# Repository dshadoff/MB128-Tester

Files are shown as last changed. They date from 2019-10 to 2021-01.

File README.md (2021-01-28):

# MB128-Tester
This project contains both a PC board to control (Backup, Restore, Test) PC Engine
Memory Base 128 devices, as well as the control software for that PC board.

The original PC board is based on an 'Adafruit Feather M0 Adalogger' microcontroller board, which
directly interfaces to PC Engine Memory Base 128 devices.

There is also an updated version which is based on the Seeed Studios Wio Terminal device, which is
more of a finished all-in-one unit with a screen.

This repository holds the software which runs on those devices, as well as the boards' design files.

The sketch was built within the Arduino IDE, but I found that the digitalWrite() and digitalRead()
functions were too slow: ~1uS per call, when I needed 3 to 4 times that speed.

Moreover, they could only manipulate one pin at a time, when I generally needed to write 2, or read 4.

As a result, you will see direct port reads/writes to the Cortex M0 (or M4) ports... see the comments at the
top of the sketch if this is confusing.

(Note: Older versions of this sketch were written for an older version of the board, which didn't have
status LEDs or pushbutton switches, and automatically started to read the MB128 at boot-up time.)

Instructions on use:
--------------------

To use any of the functionality, ensure that the MB128 is plugged into the port, and an SDCard is
inserted into the SDCard slot of the Microcontroller board.  Finally, then attach the USB cable
in order to apply power ot the board.

- M0 Adalogger board:
A short self-test will take place, and all of the LEDs will flash briefly.  Once this has completed
and the Feather's green LED is on, you may press a button.

- Wio Terminal:
A short self-test will take place, with status updates appearing on screen.  Once this has completed,
the screen will display a choice of operations (associated with the buttons across the top edge).

Backup:
-------
The device will backup the contents of the MB128 onto the SDCard, creating a file in the root
directory, with the filename: 'MB128_xx.SAV' (where 'xx' is a 2-digit number).  Multiple versions
of backups will be added to the SDCard until 99 versions have been reached.
A backup takes slightly over 10 seconds.

Restore:
--------
The device will use the highest-numbered 'MB128_xx.SAV' file in the root directory of the card,
and load the contents into the MB128.
A restore takes slightly over 10 seconds.

Test:
-----
The device will first create a temporary backup of the contents of the device, then will write,
read, and verify test patterns to all location on the MB128, finally restoring the original
contents.  The backup is saved into a file named 'TESTTEMP.BKP' in the root directory of the
SDCard.
A test takes slightly over one minute.

Error conditions:
-----------------
- If the 'SDCard Error' LED lights up at startup, there is a problem with the SDCard
- If the 'MB128 Error' LED lights up at startup, there is a problem with the MB128
(On the Wio Terminal version, clear error messages will appear on the screen).

- If either of the above LEDs go into a flashing state, this is an error which happened during
the process of reading or writing.  Please reset the device and/or turn the power off and back on

- In order to reset the device, there is a small pushbutton on the  microcontroller board. Do
not push this under normal circumstances, but you can press it if there is a flashing LED on
the MB128 reader.  If pressed, the MB128 may be interrupted in the middle of a protocol, causing
errors immedaitely afterward.  If this happens, unplug the MB128 from the reader, wait several
seconds, and plug it back in.  Then reset the microcontroller once again.

Additional information:
-----------------------
- If the USB is connected to a PC, and a terminal program is opened (19200 baud) for the
pseudo-serial port, messages indicating progress or errors will be displayed.

Original Board (Adalogger M0)
-----------------------------
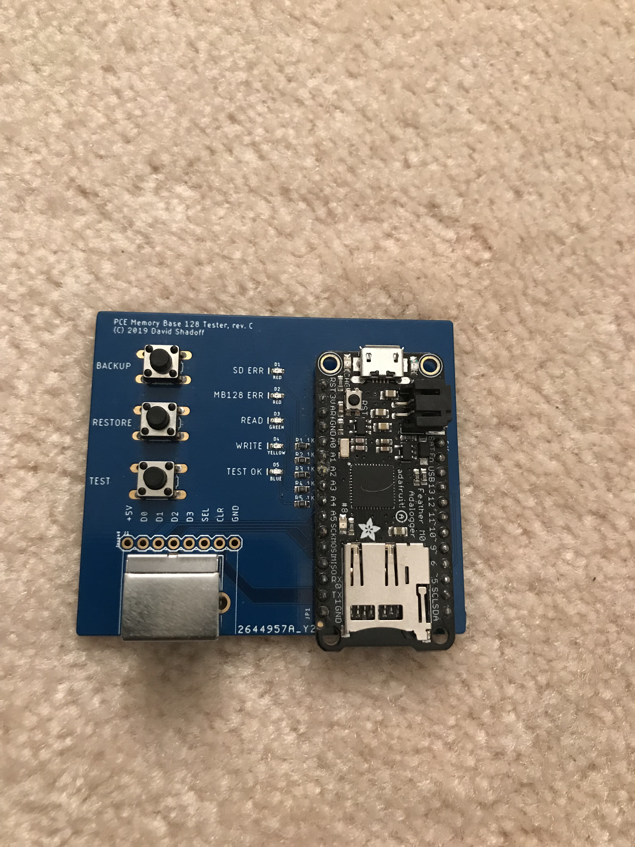
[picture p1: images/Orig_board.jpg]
Original Board


Wio Terminal (Rev. A, in use)
-----------------------------
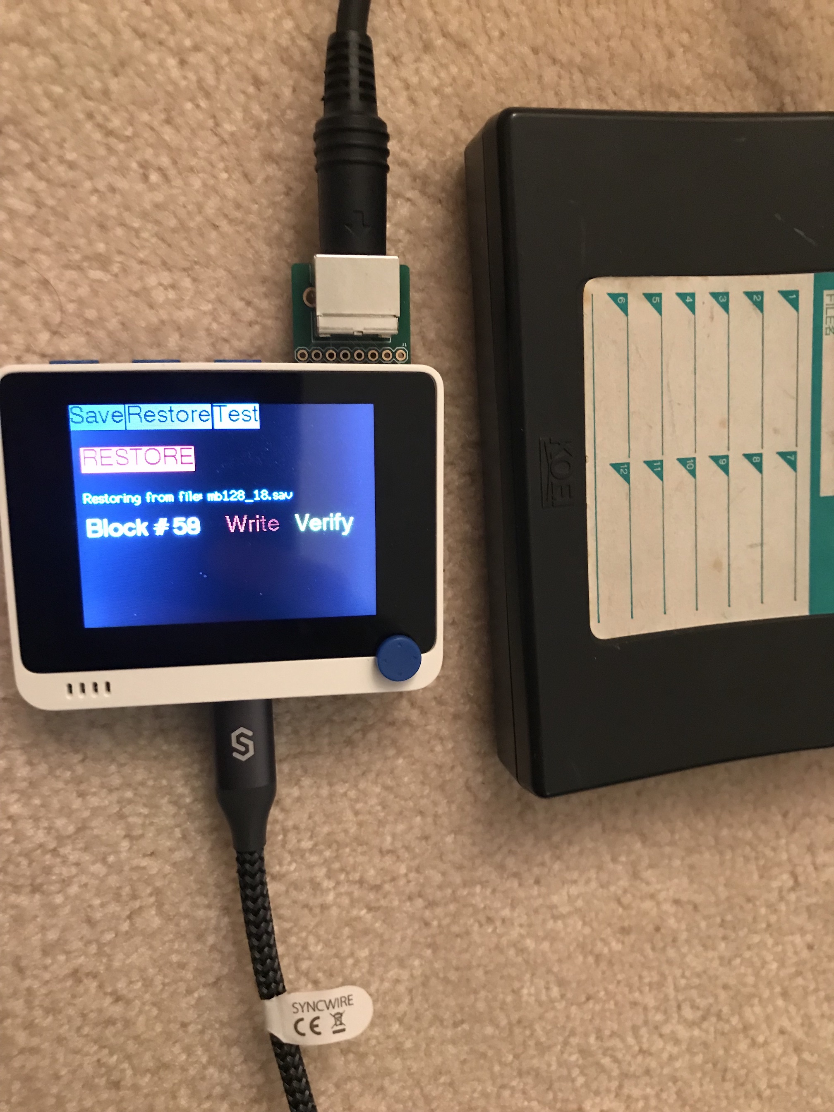
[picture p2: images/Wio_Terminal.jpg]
Wio_Terminal


Daughterboard
-------------
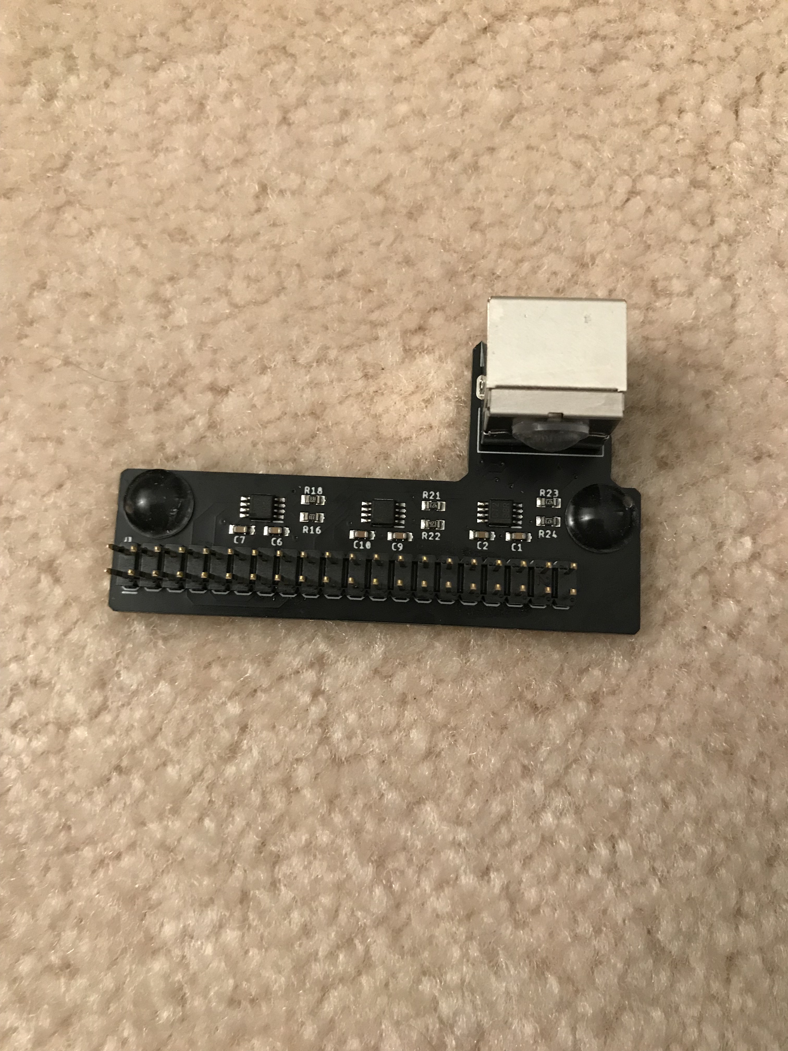
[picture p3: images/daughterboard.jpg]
Daughterboard


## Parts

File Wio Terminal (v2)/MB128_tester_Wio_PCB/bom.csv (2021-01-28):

Qty | Designator | Footprint | Comment | LCSC Part # (optional) | Description (optional)
6 | C1, C2, C6, C7, C9, C10 | C0603 | 0.1uF 50V | C14663 | Yageo CC0603KRX7R9BB104 100NF 50V 0603
2 | R16, R18 | R0603 | 330 ohm 1% | C23138 | Uniroyal Elec 0603WAF3300T5E 0603
4 | R21, R22, R23, R24 | R0603 | 47K 1% | C25819 | Uniroyal Elec 0603WAF4702T5E 0603
1 | J3 | 2X20 | Do not mount | Do not mount | Multi connection point. Often used as Generic Header-pin footprint for 0.1 inch spaced/style header connections
1 | J2 | MD80SGK | Do not mount | Do not mount | Circular DIN Connectors mini-DIN, 8P jack, rt, through hole, full shield
3 | IC1, IC2, IC3 | SM-8_2.8x3.0x0.65P | SN74LVC2T45DCTR | C22672 | 2-Bit Bus Transceiver, Translation SSOP8 SN74LVC2T45DCTR, Voltage Level Translator, Bus Transceiver LVC, 3-State 1.65

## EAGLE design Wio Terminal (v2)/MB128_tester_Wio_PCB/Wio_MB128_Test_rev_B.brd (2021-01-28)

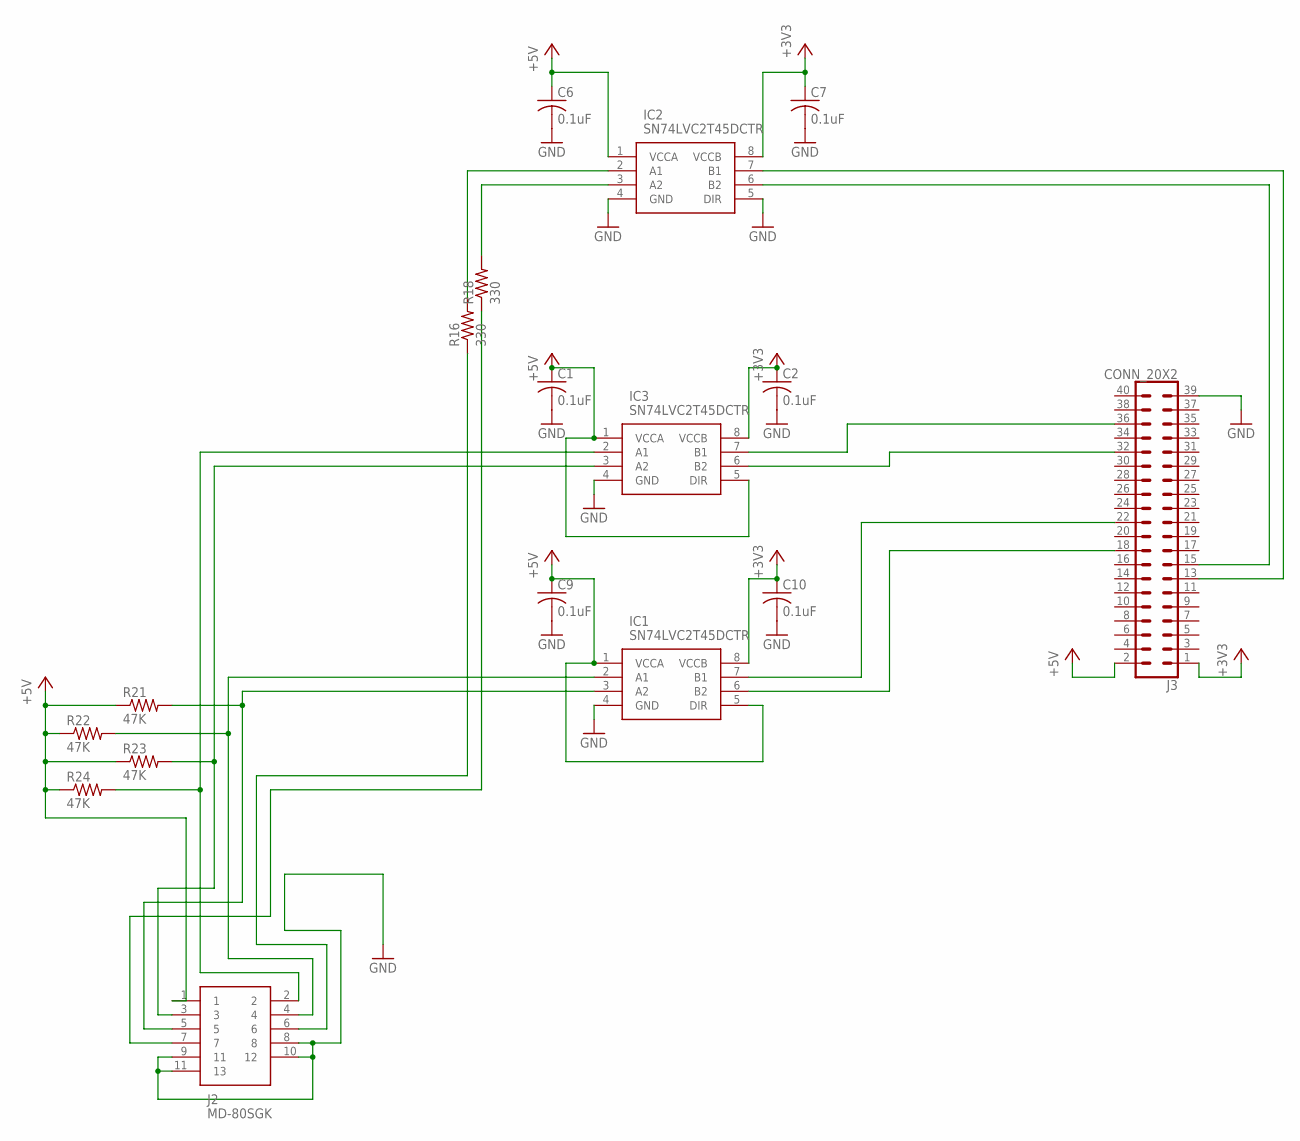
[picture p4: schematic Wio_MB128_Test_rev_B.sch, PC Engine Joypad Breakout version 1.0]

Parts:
C1, C2, C6, C7, C9, C10: 0.1uF; C0603
IC1, IC2, IC3: SN74LVC2T45DCTR; SOP65P400X130-8N
J2: MD-80SGK; MD80SGK
J3: CONN_20X2; 2X20
R16, R18: 330; R0603
R21, R22, R23, R24: 47K; R0603

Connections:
+3V3: C2.1, C7.1, C10.1, IC1.8 (VCCB), IC2.8 (VCCB), IC3.8 (VCCB), J3.1
+5V: C1.1, C6.1, C9.1, IC1.1 (VCCA), IC1.5 (DIR), IC2.1 (VCCA), IC3.1 (VCCA), IC3.5 (DIR), J2.1, J3.2, R21.1, R22.1, R23.1, R24.1
CLR: J2.7, R18.1
D11: IC1.7 (B1), J3.22
GND: C1.2, C2.2, C6.2, C7.2, C9.2, C10.2, IC1.4 (GND), IC2.4 (GND), IC2.5 (DIR), IC3.4 (GND), J2.8, J2.9 (11), J2.10 (12), J2.11 (13), J3.39
unnamed: IC2.7 (B1), J3.13
unnamed: IC3.3 (A2), J2.3, R23.2
unnamed: IC3.2 (A1), J2.2, R24.2
unnamed: IC2.6 (B2), J3.15
unnamed: IC1.6 (B2), J3.18
unnamed: IC2.2 (A1), R16.2
unnamed: IC1.2 (A1), J2.4, R22.2
unnamed: IC1.3 (A2), J2.5, R21.2
unnamed: IC2.3 (A2), R18.2
unnamed: IC3.7 (B1), J3.36
unnamed: IC3.6 (B2), J3.32
SEL: J2.6, R16.1

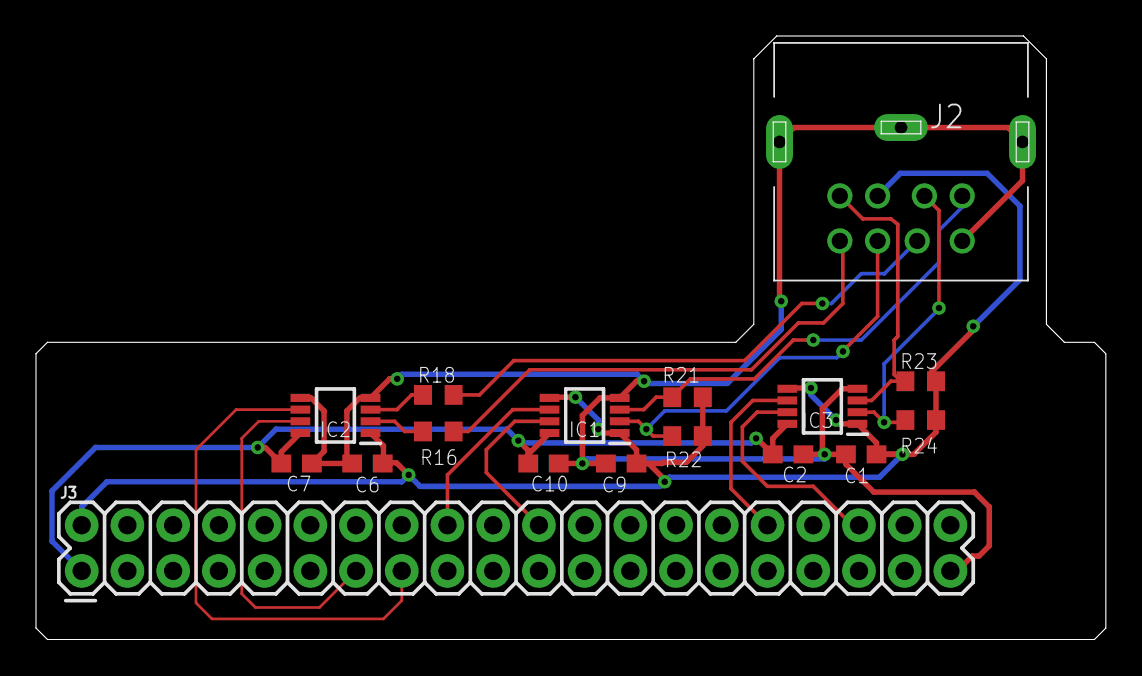
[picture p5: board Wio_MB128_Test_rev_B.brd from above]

Board: 2 copper layers, 59.4 x 33.5 mm, 17 parts (0 on the bottom side), 17 nets.

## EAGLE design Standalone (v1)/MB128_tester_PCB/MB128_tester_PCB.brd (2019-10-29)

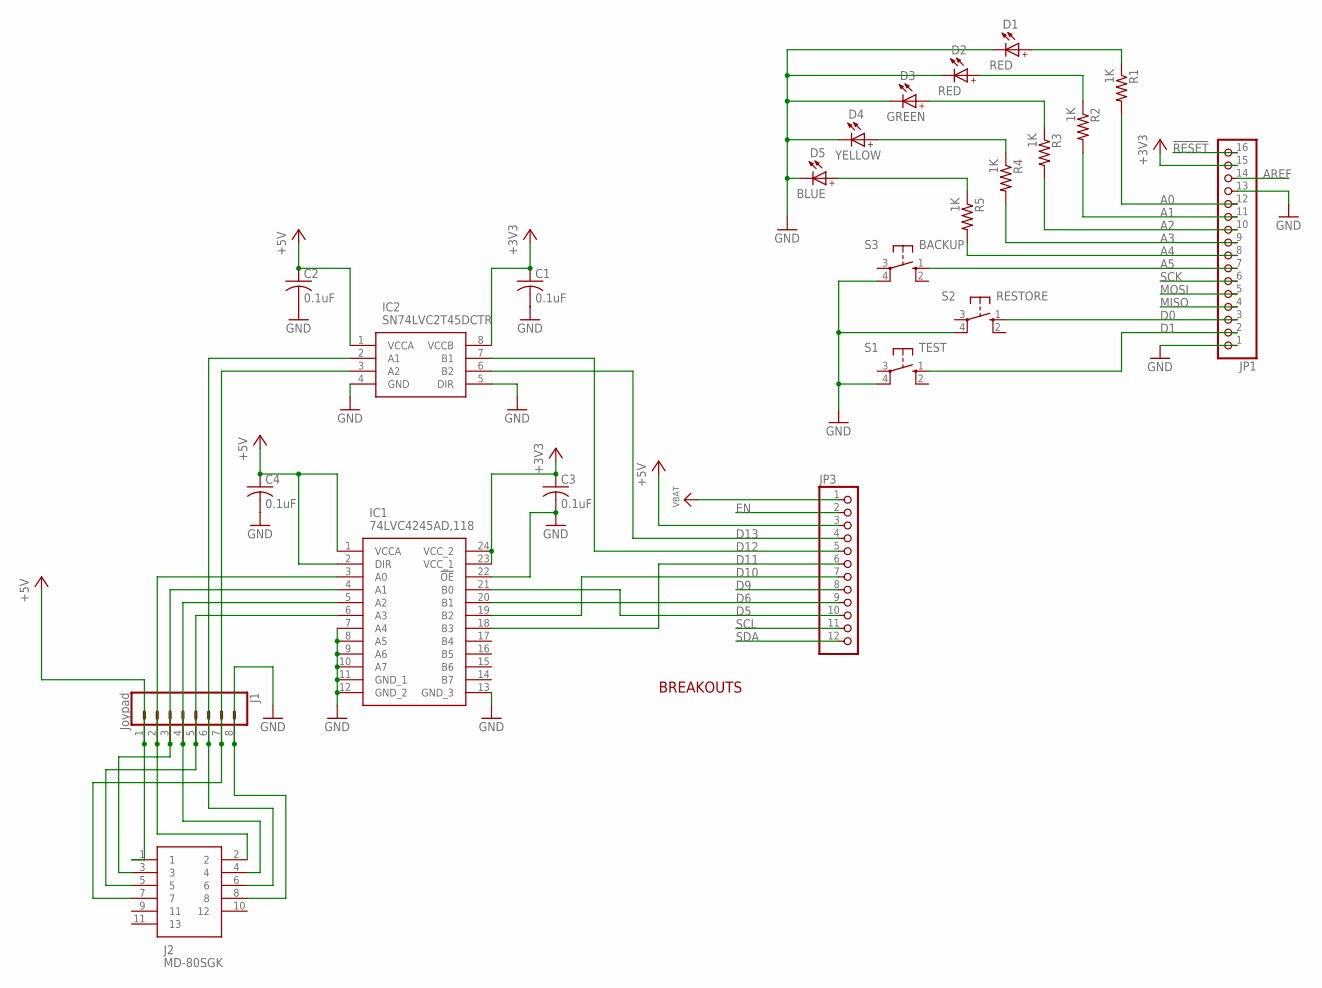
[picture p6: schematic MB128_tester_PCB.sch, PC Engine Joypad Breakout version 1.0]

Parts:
C1, C2, C3, C4: 0.1uF; C0805
D1, D2: RED; WL-SMCC_0603_R/Y/V
D3: GREEN; WL-SMCC_0603_R/Y/V
D4: YELLOW; WL-SMCC_0603_R/Y/V
D5: BLUE; WL-SMCC_0603_R/Y/V
IC1: 74LVC4245AD,118; SOIC127P1032X265-24N
IC2: SN74LVC2T45DCTR; SOP65P400X130-8N
J1: Joypad; 1X08
J2: MD-80SGK; MD80SGK
JP1: HEADER-1X16ROUND; 1X16_ROUND
JP3: HEADER-1X12; 1X12_ROUND
R1, R2, R3, R4, R5: 1K; R0603
S1: TEST; B3F-10XX
S2: RESTORE; B3F-10XX
S3: BACKUP; B3F-10XX

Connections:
!RESET: JP1.16
+3V3: C1.1, C3.1, IC1.23 (VCC_1), IC1.24 (VCC_2), IC2.8 (VCCB), JP1.15
+5V: C2.1, C4.1, IC1.1 (VCCA), IC1.2 (DIR), IC2.1 (VCCA), J1.1, J2.1, JP3.3
A0: JP1.12, R1.2
A1: JP1.11, R2.2
A2: JP1.10, R3.2
A3: JP1.9, R4.2
A4: JP1.8, R5.2
A5: JP1.7, S3.1 (S)
AREF: JP1.14
D0: JP1.3, S2.1 (S)
D1: JP1.2, S1.1 (S)
D5: IC1.21 (B0), JP3.10
D6: IC1.20 (B1), JP3.9
D9: JP3.8
D10: IC1.19 (B2), JP3.7
D11: IC1.18 (B3), JP3.6
D12: IC2.7 (B1), JP3.5
D13: IC2.6 (B2), JP3.4
EN: JP3.2
GND: C1.2, C2.2, C3.2, C4.2, D1.1 (C), D2.1 (C), D3.1 (C), D4.1 (C), D5.1 (C), IC1.7 (A4), IC1.8 (A5), IC1.9 (A6), IC1.10 (A7), IC1.11 (GND_1), IC1.12 (GND_2), IC1.13 (GND_3), IC1.22 (!OE), IC2.4 (GND), IC2.5 (DIR), J1.8, J2.8, JP1.1, JP1.13, S1.4 (P1), S2.4 (P1), S3.4 (P1)
MISO: JP1.4
MOSI: JP1.5
unnamed: D1.2 (A), R1.1
unnamed: IC1.4 (A1), J1.3, J2.3
unnamed: IC1.3 (A0), J1.2, J2.2
unnamed: IC1.5 (A2), J1.4, J2.4
unnamed: IC1.6 (A3), J1.5, J2.5
unnamed: IC2.2 (A1), J1.6, J2.6
unnamed: IC2.3 (A2), J1.7, J2.7
unnamed: D2.2 (A), R2.1
unnamed: D3.2 (A), R3.1
unnamed: D4.2 (A), R4.1
unnamed: D5.2 (A), R5.1
SCK: JP1.6
SCL: JP3.11
SDA: JP3.12
VBAT: JP3.1

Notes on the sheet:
BREAKOUTS

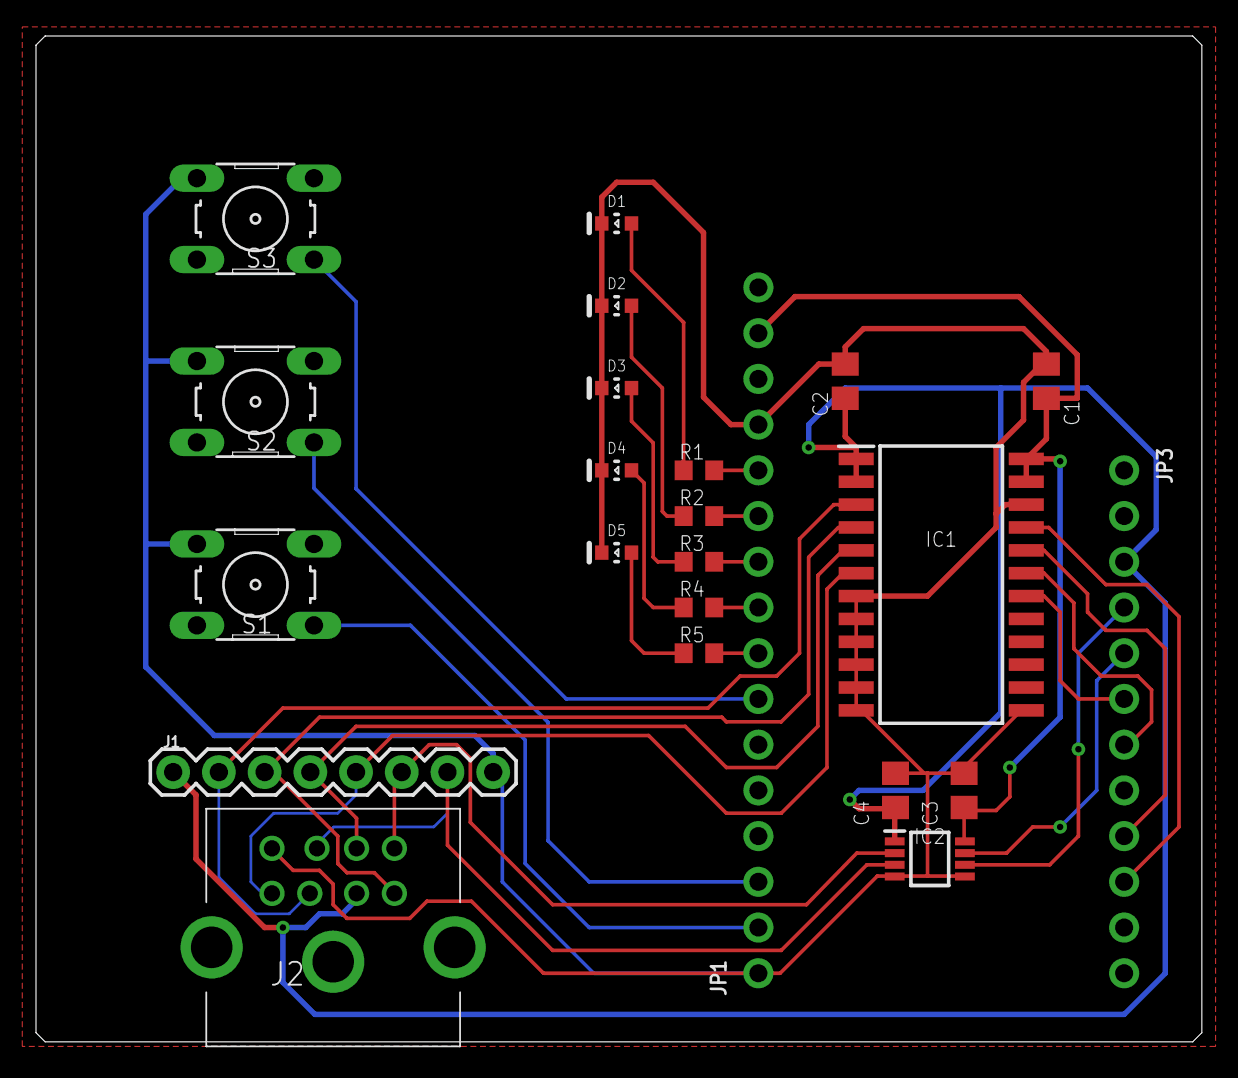
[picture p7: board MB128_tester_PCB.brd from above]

Board: 2 copper layers, 64.8 x 55.9 mm, 23 parts (0 on the bottom side), 28 nets.

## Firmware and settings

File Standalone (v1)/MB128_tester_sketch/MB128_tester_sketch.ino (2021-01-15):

#include <SD.h>

//
// This sketch implements a MB128 host
// To extract or restore the contents of the MB128 memory and perform testing
//
// This was written specifically for an Adafruit Feather M0 Adalogger, and so
// there are many dependencies which would need to be adjusted for any other
// hardware.
//

#define VERSION_NUMBER    20191201

// ------------------------
// *** HARDWARE defines ***
// ------------------------

// This sketch is made specifically for the Adafruit M0 Feather Adalogger
// We are using various pins for I/O to the MB128
//
// These are the internal mappings for those external pin identifiers
// so that we can access them directly (...and 10 times faster !)
#define IN_PORT            REG_PORT_IN0
#define OUT_PORT_SET       REG_PORT_OUTSET0
#define OUT_PORT_CLR       REG_PORT_OUTCLR0

// Inputs - raw port definitions on Feather M0 Adalogger
//
// These are used for high speed I/O, as Arduino functions
// are too slow due to library overhead
//
#define MB128_D3_INPIN     PORT_PA16    // Pin marked as D11 on M0 Feather Adalogger (D3 on PCE joypad)
#define MB128_D2_IDENTPIN  PORT_PA18    // Pin marked as D10 on M0 Feather Adalogger (D2 on PCE joypad)
#define MB128_D1_INPIN     PORT_PA20    // Pin marked as D6  on M0 Feather Adalogger (D1 on PCE joypad)
#define MB128_D0_DATAINPIN PORT_PA15    // Pin marked as D5  on M0 Feather Adalogger (D0 on PCE joypad)

// Outputs - raw port definitions on Feather M0 Adalogger
//
// These are used for high speed I/O, as Arduino functions
// are too slow due to library overhead
//
#define MB128_DATAOUTPIN   PORT_PA19    // Pin marked as D12 on M0 Feather Adalogger (SEL on PCE joypad)
#define MB128_CLOCKPIN     PORT_PA17    // Pin marked as D13 on M0 Feather Adalogger (CLR on PCE joypad)

// delay control variables
//
const bool delayMilli = false;  // if true, delay in milliseconds
const int delayShort  = 2;      // 2uS on real system
const int delayLong   = 3;      // 4uS on real system



#if defined(ADAFRUIT_FEATHER_M0)

// I/Os - these are the Arduino pin numbers
const int clockPin        = 13;  // clock to MB128 (CLR)
const int dataoutPin      = 12;  // data going to MB128 (SEL)

const int d3_inPin        = 11;  // data 3 pin from MB128
const int d2_identPin     = 10;  // data 2 - identification pin from MB128
const int d1_inPin        = 6;   // data 1 pin from MB128
const int d0_datainPin    = 5;   // data 0 - data pin from MB128 (d0)

// Chip select for on-board SDCard
const int chipSelect      = 4;

// Pins used by pushbutton switches
//
const int sw_BackupPin    = 19;
const int sw_RestorePin   = 0;
const int sw_TestPin      = 1;

// Pins used by LEDs on board(s)
//
const int led_GreenOK     = 8;
const int led_RedSDErr    = 14;
const int led_RedMB128Err = 15;
const int led_GreenRead   = 16;
const int led_YellowWrite = 17;
const int led_BlueTestOK  = 18;

#endif

const int version_num = VERSION_NUMBER;



char inChar;
boolean cardPresent;
boolean dataFilePresent;

unsigned long time_s;
unsigned long time_e;

char buffer_aa[513];
char buffer_55[513];
char buffer_mem[513];
char buffer_mem2[513];

char tempfname[16];
char lastfname[16];
char nextfname[16];
char logname[16];
int  lastfilenum = 0;
int  nextfilenum = 0;

bool debug_on = false;

File dataFile;
File logFile;

uint8_t logBuf[16];

//char to_hex(char in_nybble)
//{
//char out_char;
//  in_nybble = in_nybble & 0x0f;
//  
//  if (in_nybble < 10)
//    out_char = '0' + in_nybble;
//  else
//    out_char = 'A' - 10 + in_nybble;
//    
//  return(out_char);
//}


void delay_short()
{
  if (delayShort == 0)
    return;

  if (delayMilli)
    delay(delayShort);
  else
    delayMicroseconds(delayShort);
}

void delay_long()
{
  if (delayLong == 0)
    return;

  if (delayMilli)
    delay(delayLong);
  else
    delayMicroseconds(delayLong);
}

void log_access(char sendrec, bool clk, bool sel)
{
  uint32_t  inport;
  
  //** READ the return ports
  inport = IN_PORT;

  if (debug_on) {
    logBuf[0] = sendrec;
    logBuf[1] = ' ';
    logBuf[2] = clk ? '1' : '0';
    logBuf[3] = sel ? '1' : '0';


    logBuf[4] = ' ';      // space

    logBuf[5] = (inport & MB128_D3_INPIN) ? '1' : '0';
    logBuf[6] = (inport & MB128_D2_IDENTPIN) ? '1' : '0';
    logBuf[7] = (inport & MB128_D1_INPIN) ? '1' : '0';
    logBuf[8] = (inport & MB128_D0_DATAINPIN) ? '1' : '0';

    logBuf[9] = 0x0d;
    logBuf[10] = 0x0a;
    logFile.write(&logBuf[0], 10);
  }
}


void mb128_send_bit(bool outbit)
{
// ***
//  following code is rapid-access for these Arduino func's:
//  digitalWrite(clockPin, LOW);
  OUT_PORT_CLR = MB128_CLOCKPIN;
  
//  digitalWrite(dataoutPin, outbit);
  if (outbit)
    OUT_PORT_SET = MB128_DATAOUTPIN;
  else
    OUT_PORT_CLR = MB128_DATAOUTPIN;

  delay_short();
  
//  digitalWrite(clockPin, HIGH);
  OUT_PORT_SET = MB128_CLOCKPIN;

  delay_long();

  log_access('S', true, outbit);

//  digitalWrite(clockPin, LOW);
  OUT_PORT_CLR = MB128_CLOCKPIN;

  delay_short();

  log_access('S', false, outbit);
}

void mb128_send_byte(char outbyte)
{
bool outbit;
char i = 8;

  if (debug_on) {
    logFile.print("Send Byte 0x");
    logFile.print(((outbyte >> 4)& 0x0f), HEX);
    logFile.println((outbyte & 0x0f), HEX);
  }

  while (i > 0) {
    if (outbyte & 0x01)
      outbit = true;
    else
      outbit = false;

// ***
//  following code is rapid-access for these Arduino func's:
//    digitalWrite(clockPin, LOW);
    OUT_PORT_CLR = MB128_CLOCKPIN;

//    digitalWrite(dataoutPin, outbit);
    if (outbit)
      OUT_PORT_SET = MB128_DATAOUTPIN;
    else
      OUT_PORT_CLR = MB128_DATAOUTPIN;

    delay_short();

//    digitalWrite(clockPin, HIGH);
    OUT_PORT_SET = MB128_CLOCKPIN;

    delay_long();
    
    log_access('S', true, outbit);

//    digitalWrite(clockPin, LOW);
    OUT_PORT_CLR = MB128_CLOCKPIN;
  
    delay_short();

    log_access('S', false, outbit);

    outbyte = outbyte >> 1;
    i--;
  }
  logFile.println();

}

boolean mb128_read_bit()
{
bool inbit;
uint32_t inport;

// ***
//  following code is rapid-access for these Arduino func's:
//  digitalWrite(clockPin, LOW);
  OUT_PORT_CLR = MB128_CLOCKPIN;

//  digitalWrite(dataoutPin, LOW);
  OUT_PORT_CLR = MB128_DATAOUTPIN;
  delay_short();

//  digitalWrite(clockPin, HIGH);
  OUT_PORT_SET = MB128_CLOCKPIN;
  delay_short();

  log_access('R', true, false);

//  inbit = digitalRead(d0_datainPin);
  inbit = (IN_PORT & MB128_D0_DATAINPIN);

//  digitalWrite(clockPin, LOW);
  OUT_PORT_CLR = MB128_CLOCKPIN;
  delay_short();

  log_access('R', false, false);

  return(inbit);
}

char mb128_read_byte()
{
bool inbit;
char inbyte = 0;
char i = 8;

  if (debug_on) {
    logFile.println("Read Byte");
  }

  while (i > 0) {

// ***
//  following code is rapid-access for these Arduino func's:
//    digitalWrite(clockPin, LOW);
    OUT_PORT_CLR = MB128_CLOCKPIN;

//    digitalWrite(dataoutPin, LOW);
    OUT_PORT_CLR = MB128_DATAOUTPIN;

    delay_short();
    
//    digitalWrite(clockPin, HIGH);
    OUT_PORT_SET = MB128_CLOCKPIN;
    delay_short();

    log_access('R', true, false);

//    inbit = digitalRead(d0_datainPin);
    inbit = (IN_PORT & MB128_D0_DATAINPIN);

//    digitalWrite(clockPin, LOW);
    OUT_PORT_CLR = MB128_CLOCKPIN;
    delay_short();

    log_access('R', false, false);

    inbyte = inbyte >> 1;

    if (inbit == true)
      inbyte = inbyte | 0x80;
    else
      inbyte = inbyte & 0x7f;
    
    i--;
  }
  
  if (debug_on) {
    logFile.print("Byte Read = 0x");
    logFile.print(((inbyte >> 4)& 0x0f), HEX);
    logFile.println((inbyte & 0x0f), HEX);
    logFile.println();
  }

  return(inbyte);
}

void joyport_init()
{
  // simulate a joyport scan across 5 joypads
  //
  if (debug_on)
    logFile.println("joyport init");
  
  mb128_send_bit(true);
  
  if (debug_on)
    logFile.println("");
  
  delay_long();
  digitalWrite(dataoutPin, LOW);
  delay_short();
  digitalWrite(dataoutPin, HIGH);
  delay_short();
  digitalWrite(dataoutPin, LOW);
  delay_short();
  digitalWrite(dataoutPin, HIGH);
  delay_short();
  digitalWrite(dataoutPin, LOW);
  delay_short();
  digitalWrite(dataoutPin, HIGH);
  delay_short();
  digitalWrite(dataoutPin, LOW);
  delay_short();
  digitalWrite(dataoutPin, HIGH);
  delay_short();
  digitalWrite(dataoutPin, LOW);
  delay_short();
  digitalWrite(dataoutPin, HIGH);
  delay(10);
}

bool mb128_detect()
{
char i = 4;   // number of retries
char joy_out = 0;

  if (debug_on) {
    logFile.println("Detect - write 0xa8");
  }

  while (i > 0) {
    mb128_send_byte(0xa8);

    if (debug_on) {
      logFile.println("Detect - read bit #1");
    }

    mb128_send_bit(false);
    
// ***
//    if (digitalRead(d2_identPin))
    if (IN_PORT & MB128_D2_IDENTPIN)
      joy_out = joy_out | 0x40;

//    if (digitalRead(d0_datainPin))
    if (IN_PORT & MB128_D0_DATAINPIN)
      joy_out = joy_out | 0x10;
  
    if (debug_on) {
      logFile.println("Detect - read bit #2");
    }
    
    mb128_send_bit(true);

//    if (digitalRead(d2_identPin))
    if (IN_PORT & MB128_D2_IDENTPIN)
      joy_out = joy_out | 0x4;

//    if (digitalRead(d0_datainPin))
    if (IN_PORT & MB128_D0_DATAINPIN)
      joy_out = joy_out | 0x1;
  
    if (joy_out == 0x04) {
      if (debug_on)
        logFile.println("");

      return(true);
    }
    else {
      Serial.print("0xA8 not acknowledged... ");
      Serial.print("joy_out = ");
      Serial.println(joy_out, HEX);

      if (debug_on) {
        logFile.print("0xA8 not acknowledged... ");
        logFile.print("joy_out = ");
        logFile.println(joy_out, HEX);
      }
    }
  
    joy_out = 0;
    i = i -1;
  }

  // send three zero bits if it was not detected
  if (debug_on) {
    logFile.println("Detect - send 3 trailing bits");
  }

  mb128_send_bit(false);
  mb128_send_bit(false);
  mb128_send_bit(false);

  if (debug_on) {
    logFile.println("");
  }
  
  return(false);
}

bool mb128_boot()
{
char i = 8;  // number of retries
bool found = false;
bool temp;

  while (i > 0) {
    found = mb128_detect();
    if (found)
      break;
    i--;
  }
  if ((i == 0) && (!found))
    return(false);

  if (debug_on) {
    logFile.println("Boot lead");
  }
  
  mb128_send_bit(true);   // 1
  mb128_send_bit(false);  // 0
  mb128_send_bit(false);  // 0
  
  if (debug_on) {
    logFile.println("Boot Byte 0x00");
  }
  
  mb128_send_byte(0x00);  // 0x00
  
  if (debug_on) {
    logFile.println("Boot Byte 0x01");
  }

  mb128_send_byte(0x01);  // 0x01
  
  if (debug_on) {
    logFile.println("Boot Byte 0x00");
  }

  mb128_send_byte(0x00);  // 0x00
  
  if (debug_on) {
    logFile.println("Boot 4 bits");
  }

  mb128_send_bit(false);  // 0
  mb128_send_bit(false);  // 0
  mb128_send_bit(false);  // 0
  mb128_send_bit(false);  // 0
  
  if (debug_on) {
    logFile.println("Boot readbit");
  }

  temp = mb128_read_bit();

//  Serial.print("boot readbit = ");
//  if (temp)
//    Serial.println("1");
//  else
//    Serial.println("0");
  
  if (debug_on) {
    logFile.println("Boot trail 3 bits");
  }

  mb128_send_bit(false);  // 0
  mb128_send_bit(false);  // 0
  mb128_send_bit(false);  // 0

  if (debug_on) {
    logFile.println("");
  }

  return(true);
}

#define MB128_READ_SECTOR   true
#define MB128_WRITE_SECTOR  false

void mb128_rdwr_sector_num(bool rdwr, char sector_num)
{
  logFile.println("Read-write header");
  mb128_send_bit(rdwr);   // 1 = read; 0 = write

  logFile.println("Read-write address");
  mb128_send_bit(false);  // 0
  mb128_send_bit(false);  // 0
  mb128_send_byte(sector_num);  // sector number

//TODO: Fix this section to explain write of length properly
//
  logFile.println("Read-write length");
  mb128_send_byte(0x00);  // 0x00
  mb128_send_byte(0x10);  // 0x10
  
  mb128_send_bit(false);  // 0
  mb128_send_bit(false);  // 0
  mb128_send_bit(false);  // 0
  mb128_send_bit(false);  // 0  
  logFile.println("");
}

// set start addr
void mb128_rdwr_addr_len(bool rdwr, int start_addr, long bytes, char bits)
{
  int i;
  long bitmask;
  
  logFile.println("Read-write header");
  mb128_send_bit(rdwr);   // 1 = read; 0 = write

  logFile.println("Read-write address");  // sent as multiples of 128 bytes
  bitmask = 1;
  for (i = 0; i < 10; i++) {
    
    if (start_addr & bitmask) {
      mb128_send_bit(true);
    }
    else {
      mb128_send_bit(false);
    }
    bitmask <<= 1;
  }

  // length is first sent as number of bits, fllowed by number of bytes
  logFile.println("Number of bits");
  bitmask = 1;
  for (i = 0; i < 3; i++) {
    
    if (bits & bitmask) {
      mb128_send_bit(true);
    }
    else {
      mb128_send_bit(false);
    }
    bitmask <<= 1;
  }
  
  logFile.println("Number of bytes");
  bitmask = 1;
  for (i = 0; i < 17; i++) {
    
    if (bytes & bitmask) {
      mb128_send_bit(true);
    }
    else {
      mb128_send_bit(false);
    }
    bitmask <<= 1;
  }

  logFile.println("");
}

void mb128_read_to_buffer_512(char * bufptr)
{
int i, j;
char read_byte;
char disp_char;
char char_buf[16];

   for (i = 0; i < 512; i+=16 ) {
//     Serial.print(((i >> 8) & 0x0f), HEX);
//     Serial.print(((i >> 4) & 0x0f), HEX);
//     Serial.print((i & 0x0f), HEX);
//     Serial.print(": ");
     for (j = 0; j < 16; j++) {
       read_byte = mb128_read_byte();

       // put it into the return buffer
       *(bufptr) = read_byte;
       bufptr++;
       
       if ((read_byte < 0x20) || (read_byte > 0x7f))
         disp_char = '.';
       else
         disp_char = read_byte;
          
       char_buf[j] = disp_char;

//       Serial.print(((read_byte >> 4) & 0x0f), HEX);
//       Serial.print((read_byte & 0x0f), HEX);
//       Serial.print(" ");
     }
     for (j = 0; j < 16; j++) {
//       Serial.print(char_buf[j]);        
     }
//     Serial.println("");
   }
}

bool mb128_read_sector(char sector, char *bufptr)
{
   if (!mb128_detect())
     return(false);

   digitalWrite(led_GreenOK, LOW);
   digitalWrite(led_GreenRead, HIGH);

   mb128_rdwr_sector_num(MB128_READ_SECTOR, sector);
   mb128_read_to_buffer_512(bufptr);

   digitalWrite(led_GreenRead, LOW);
   digitalWrite(led_GreenOK, HIGH);

// trailing bits (3 bits for reads)
   mb128_send_bit(false);  // 0
   mb128_send_bit(false);  // 0
   mb128_send_bit(false);  // 0
   
   return(true);
}

bool mb128_read_sectors(char start_sector, int num_sectors)
{
int i, j;
char read_byte;
char disp_char;
char curr_sector = start_sector;
char char_buf[16];
char read_buf[512];

//NOTE: Where multiple sectors are read, each sector is requsted one-by-one
//      rather than using a single large read
//
  while (num_sectors > 0) {

    logFile.print("Read sector 0x");
    logFile.print(((curr_sector >> 4)& 0x0f), HEX);
    logFile.println((curr_sector & 0x0f), HEX);

    Serial.print("Sector #");
    Serial.print(((curr_sector >> 4) & 0x0f), HEX);
    Serial.println((curr_sector & 0x0f), HEX);

    if (!mb128_read_sector(curr_sector, read_buf))
      return(false);

    if (cardPresent)
      dataFile.write(read_buf, 512);

    curr_sector++;
    num_sectors--;
    delay(1);
  }

  return(true);
}

void mb128_write_from_buffer_512(char * bufptr)
{
int i, j;
char read_byte;
char disp_char;
char char_buf[16];

   for (i = 0; i < 512; i+=16 ) {
//     Serial.print(((i >> 8) & 0x0f), HEX);
//     Serial.print(((i >> 4) & 0x0f), HEX);
//     Serial.print((i & 0x0f), HEX);
//     Serial.print(": ");

     for (j = 0; j < 16; j++) {
       read_byte = *(bufptr);
       mb128_send_byte(read_byte);
       bufptr++;

       if ((read_byte < 0x20) || (read_byte > 0x7f))
         disp_char = '.';
       else
         disp_char = read_byte;
         
       char_buf[j] = disp_char;

//       Serial.print(((read_byte >> 4) & 0x0f), HEX);
//       Serial.print((read_byte & 0x0f), HEX);
//       Serial.print(" ");
     }
     for (j = 0; j < 16; j++) {
//       Serial.print(char_buf[j]);        
     }
//     Serial.println("");
   }
}

bool mb128_write_sector(char sector, char *bufptr)
{
bool temp1, temp2;
int sector_num;

   if (!mb128_detect()) {
     Serial.println("Write_sector - failed to detect");
     return(false);
   }

   digitalWrite(led_GreenOK, LOW);
   digitalWrite(led_YellowWrite, HIGH);

   mb128_rdwr_sector_num(MB128_WRITE_SECTOR, sector);
   mb128_write_from_buffer_512(bufptr);

   digitalWrite(led_YellowWrite, LOW);
   digitalWrite(led_GreenOK, HIGH);

// trailing bits (3 + 2 bits for writes):

   temp1 = mb128_read_bit();
   temp2 = mb128_read_bit();

   mb128_send_bit(false);  // 0
   mb128_send_bit(false);  // 0
   mb128_send_bit(false);  // 0

// post-write bit #1 indicates device type:
// 0 = save-kun
// 1 = memory base 128

//   if (!temp1) {
//     logFile.print("Write sector 0x");
//     sector_num = sector;
//     logFile.print(sector_num);
//     logFile.println(", sector write operation, post-sector bit#1 != 1... Fail"); 
//     Serial.println("Write_sector - post-sector bit #1 != 1 - Fail");
//     return(false);
//   }

// post-write bit #2 was thought to indicate success/failure, but it
// appears not to be the case, based on MooZ's experience with a Save-kun
//
//   if (temp2) {
//     logFile.print("Write sector 0x");
//     sector_num = sector;
//     logFile.print(sector_num);
//     logFile.println(", sector write operation, post-sector bit#2 != 0... Fail"); 
//     Serial.println("Write_sector - post-sector bit #2 != 0 - Fail");
//     return(false);
//   }

   return(true);
}

bool mb128_write_sectors(char start_sector, int num_sectors)
{
int i, j;
char read_byte;
char disp_char;
char curr_sector = start_sector;
char write_buf[512];
char char_buf[16];
bool temp;


//  if (!dataFilePresent) {
//    return(false);
//  }

  while (num_sectors > 0) {

    dataFile.readBytes(write_buf, 512);

    logFile.print("Write sector 0x");
    logFile.print(((curr_sector >> 4)& 0x0f), HEX);
    logFile.println((curr_sector & 0x0f), HEX);

    Serial.print("Sector #");
    Serial.print(((curr_sector >> 4) & 0x0f), HEX);
    Serial.println((curr_sector & 0x0f), HEX);

    if (!mb128_write_sector(curr_sector, write_buf))
      return(false);

    curr_sector++;
    num_sectors--;
    delay(1);
  }

  return(true);
}

void write_to_mb128()
{
  dataFilePresent = false;

  Serial.println("Writing to MB128");
  
  if (!cardPresent) {
    Serial.println("No Card");
    return;
  }

  if (!SD.exists("mb128.bkp")) {
    Serial.println("mb128.bkp does not exist.");
    return;
  }

  Serial.println("Opening mb128.bkp");
  dataFile = SD.open("mb128.bkp", FILE_READ);
  dataFilePresent = true;   // I should probably have checked the result of the open...

//  Serial.println("Initialize joyport");
//  joyport_init();
//  joyport_init();
  
  Serial.println("Detect MB128");
  if (mb128_boot() == true)
    Serial.println("booted");
  else {
    Serial.println("boot failure");
    dataFile.close();
    return;
  }  

  Serial.println("Write sectors");
  if (mb128_write_sectors(0,256) == false)
    Serial.println("Error");
  else
    Serial.println("Success !");

  dataFile.close();
}

void flourish()
{
  digitalWrite(clockPin, HIGH);
  digitalWrite(led_GreenOK, HIGH);
  digitalWrite(led_RedSDErr, HIGH);
  digitalWrite(led_RedMB128Err, HIGH);
  digitalWrite(led_GreenRead, HIGH);
  digitalWrite(led_YellowWrite, HIGH);
  digitalWrite(led_BlueTestOK, HIGH);
  delay(600);

  digitalWrite(clockPin, LOW);
  digitalWrite(led_GreenOK, LOW);
  digitalWrite(led_RedSDErr, LOW);
  digitalWrite(led_RedMB128Err, LOW);
  digitalWrite(led_GreenRead, LOW);
  digitalWrite(led_YellowWrite, LOW);
  digitalWrite(led_BlueTestOK, LOW);
  delay(180);

  digitalWrite(led_BlueTestOK, HIGH);
  delay(180);
  digitalWrite(led_BlueTestOK, LOW);

  digitalWrite(led_YellowWrite, HIGH);
  delay(180);
  digitalWrite(led_YellowWrite, LOW);

  digitalWrite(led_GreenRead, HIGH);
  delay(180);
  digitalWrite(led_GreenRead, LOW);

  digitalWrite(led_RedMB128Err, HIGH);
  delay(180);
  digitalWrite(led_RedMB128Err, LOW);

  digitalWrite(led_RedSDErr, HIGH);
  delay(180);
  digitalWrite(led_RedSDErr, LOW);

  delay(200);

  digitalWrite(led_GreenOK, HIGH);
}

// flash_error is a terminal state - it blinks forever
//             (until reset is pressed)
//
void flash_error(int led)
{
  digitalWrite(led_GreenOK, LOW);
  
  while (1) {
    digitalWrite(led, HIGH);
    delay(200);
    digitalWrite(led, LOW);
    delay(200);
  }
}

void blink_error(int led)
{
  int i;
  
  digitalWrite(led_GreenOK, LOW);
  
  for (i = 0; i < 5; i++) {
    digitalWrite(led, HIGH);
    delay(100);
    digitalWrite(led, LOW);
    delay(100);
  }
  digitalWrite(led_GreenOK, HIGH);
}

void find_filename()
{
  int i, j;

  lastfilenum = -1;

  digitalWrite(led_GreenOK, LOW);
  digitalWrite(led_BlueTestOK, LOW);
  digitalWrite(led_GreenRead, HIGH);

  // Need to re-initialize each time the card might be replaced
  //
  if (!SD.begin(chipSelect)) {
    Serial.println("Card failed or not present");
    flash_error(led_RedSDErr);
  }

  if (SD.exists("mb128.dbg"))
    debug_on = true;
  else
    debug_on = false;

  // Since scanning for 100 files is time-consuming,
  // check 10 by 10, then one by one:
  //
  for (i = 0; i < 100; i+=10) {

    lastfname[6] = (i/10) + '0';
    lastfname[7] = (i%10) + '0';
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
void loop() {
  int rdval;

  if (digitalRead(sw_BackupPin) == LOW) {
    backup_button();
  }

  if (digitalRead(sw_RestorePin) == LOW) {
    restore_button();
  }

  if (digitalRead(sw_TestPin) == LOW) {
    test_button();
  }

  if (Serial.available()) {
    inChar = Serial.read();
    if (inChar == 'W') {
      write_to_mb128();
    }
    else {
      Serial.print("Recieved: ");
      Serial.println(inChar);
      Serial.println("W = Write to MB128 (from MB128.BKP); R = Read from MB128 (into MB128.SAV)");
      Serial.println("Please use a valid command");
    }
  }
}

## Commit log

2019-08-26 Initial commit This is the version prior to adding pushbuttons and LEDs to the circuit board
2019-09-01 Rough-in support for new board - switches and LEDs Also add TODOs for follow-up items
2019-10-29 Add PC Board design (Eagle) & gerbers
    [MB128_tester_PCB.brd, MB128_tester_PCB.sch]
2019-10-29 Fix sketch name to match overall project
    [MB128_tester_sketch.ino]
2021-01-15 Update version
    - Change the hierarchy to include both old and new versions
    - Add Wio version with screen I/O
    - Add Wio daughterboard
    [MB128_tester_PCB.brd, MB128_tester_PCB.sch, Wio_MB128_Test_rev_A.brd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]
2021-01-28 Update board revision for Wio Terminal
    - Update board revision for Wio Terminal, including the files required for JLCPCB to perform SMD assembly of the board.
    [Wio_MB128_Test_rev_B.brd, Wio_MB128_Test_rev_B.sch, assembly.csv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]

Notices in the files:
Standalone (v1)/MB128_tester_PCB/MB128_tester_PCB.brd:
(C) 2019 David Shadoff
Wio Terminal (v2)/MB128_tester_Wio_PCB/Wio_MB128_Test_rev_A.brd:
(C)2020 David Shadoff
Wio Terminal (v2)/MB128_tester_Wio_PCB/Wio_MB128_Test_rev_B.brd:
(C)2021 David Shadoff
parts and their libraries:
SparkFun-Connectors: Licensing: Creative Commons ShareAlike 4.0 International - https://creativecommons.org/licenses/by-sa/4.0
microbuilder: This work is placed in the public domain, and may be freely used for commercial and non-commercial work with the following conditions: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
